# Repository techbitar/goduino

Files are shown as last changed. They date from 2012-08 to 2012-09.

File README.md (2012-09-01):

GOduino III Robot Controller

BACKGROUND

The GOduino III is an Arduino compatible Open Source Hardware robot controller. A while ago, I set out to design a simple robot controller that I can use for both my microcontroller and robotics workshops as well as for my personal tech projects. 

The GOduino III is an Arduino clone. It's built with DIP ICs and through-hole components for ease of assembly and repair.  Also, The GOduino III can be inserted onto a breadboard making it possible to use jumper wires to connect sensors and other parts. The robot controller can handle 2 small servos and 2 DC brushed motors (max 1.2A for each motor).

DESIGNER

Hazim Bitar (techbitar at gmail dot com) 

ORGANIZATION

PIN 13 Protospace (facebook.com/pin13)

DATE

July 12, 2012

CREDIT

Jafar Quttaineh: QA, controller design.
Badr Ghatasheh: QA, variable naming conventions.
Limor Fried: Tutorials and open source products (adafruit.com)

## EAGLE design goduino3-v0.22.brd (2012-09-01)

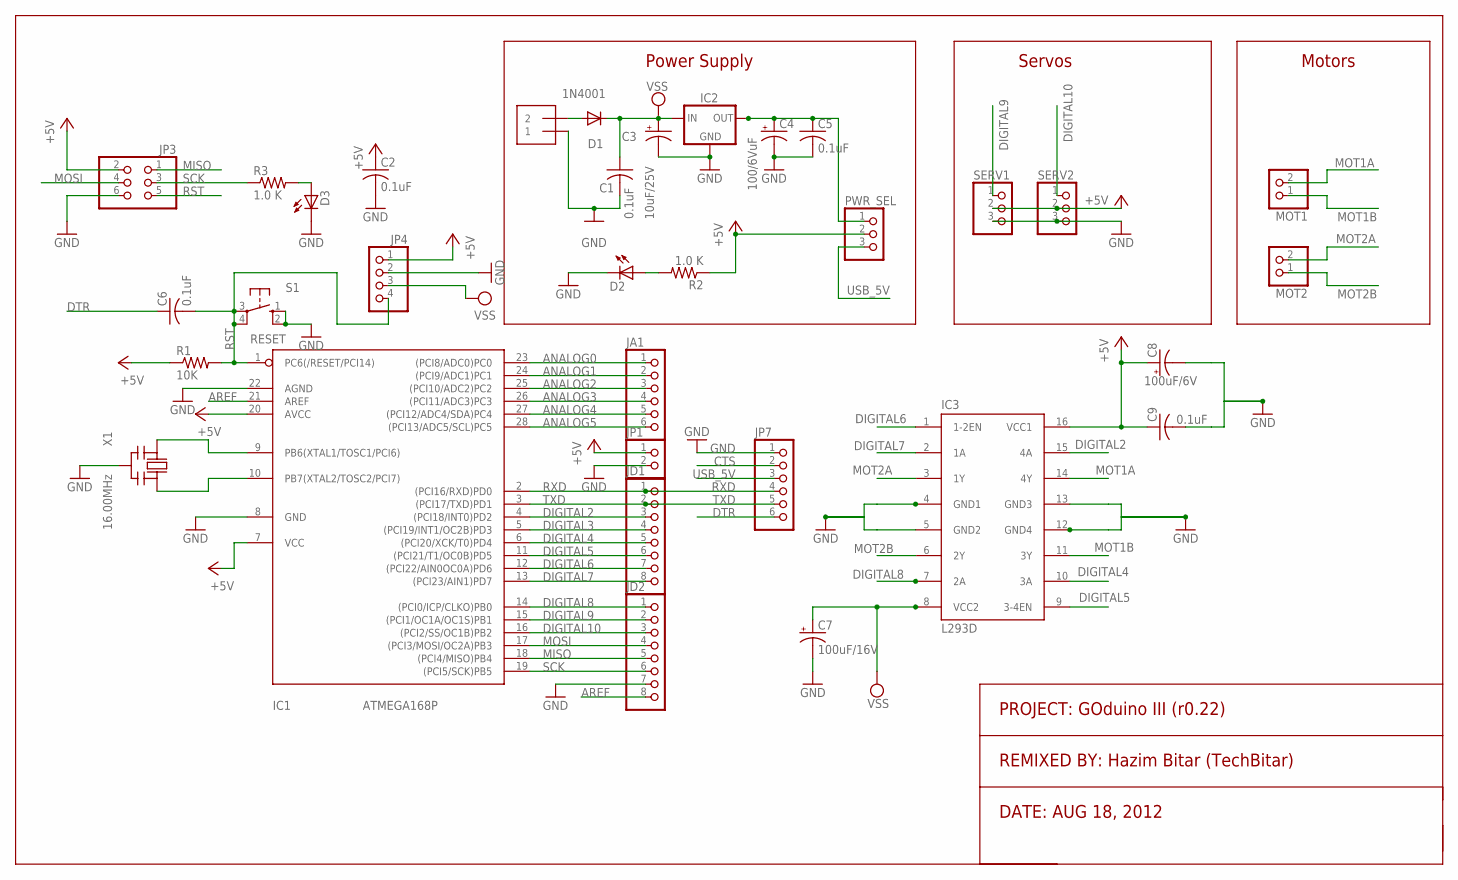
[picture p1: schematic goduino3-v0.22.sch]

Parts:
C1, C2, C5, C6, C9: 0.1uF; C025-025X050
C3: 10uF/25V; E2,5-6
C4: 100/6VuF; E2,5-6
C7: 100uF/16V; E2,5-6
C8: 100uF/6V; E2,5-5
D1: 1N4001; DO41-10
D2: LED3MM
D3: Green; LED3MM
IC1: ATMEGA168P; DIL28/3
IC2: 78XXS
IC3: L293D; DIL16
J2: 1X2-3.5MM
JA1: PINHD-1X6CB; 1X06-CLEANBIG
JD1, JD2: PINHD-1X8CLEANBIG; 1X08-CLEANBIG
JP1: PINHD-1X2CB; 1X02-CB
JP3: PINHD-2X3; 2X03
JP4: PINHD-1X4CB; 1X04-CB
JP7: PINHD-1X6CLEAN; 1X06-CLEAN
MOT1, MOT2: PINHD-1X2CB; 1X02-CB
PWR_SEL: PINHD-1X3; 1X03
R1: 10K; 0207/5V
R2, R3: 1.0 K; 0207/5V
S1: RESET; B3F-10XX
SERV1, SERV2: PINHD-1X3; 1X03
X1: 16.00MHz; CERM_OSC

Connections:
+5V: C2.1, C8.+, C9.1, IC1.7 (VCC), IC1.20 (AVCC), IC3.16 (VCC1), JP1.1, JP3.2, JP4.1, PWR_SEL.2, R1.1, R2.1, SERV1.2, SERV2.2
ANALOG0: IC1.23 ((PCI8/ADC0)PC0), JA1.1
ANALOG1: IC1.24 ((PCI9/ADC1)PC1), JA1.2
ANALOG2: IC1.25 ((PCI10/ADC2)PC2), JA1.3
ANALOG3: IC1.26 ((PCI11/ADC3)PC3), JA1.4
ANALOG4: IC1.27 ((PCI12/ADC4/SDA)PC4), JA1.5
ANALOG5: IC1.28 ((PCI13/ADC5/SCL)PC5), JA1.6
AREF: IC1.21 (AREF), JD2.8
CTS: JP7.2
DIGITAL2: IC1.4 ((PCI18/INT0)PD2), IC3.15 (4A), JD1.3
DIGITAL3: IC1.5 ((PCI19/INT1/OC2B)PD3), JD1.4
DIGITAL4: IC1.6 ((PCI20/XCK/T0)PD4), IC3.10 (3A), JD1.5
DIGITAL5: IC1.11 ((PCI21/T1/OC0B)PD5), IC3.9 (3-4EN), JD1.6
DIGITAL6: IC1.12 ((PCI22/AIN0OC0A)PD6), IC3.1 (1-2EN), JD1.7
DIGITAL7: IC1.13 ((PCI23/AIN1)PD7), IC3.2 (1A), JD1.8
DIGITAL8: IC1.14 ((PCI0/ICP/CLKO)PB0), IC3.7 (2A), JD2.1
DIGITAL9: IC1.15 ((PCI1/OC1A/OC1S)PB1), JD2.2, SERV1.1
DIGITAL10: IC1.16 ((PCI2/SS/OC1B)PB2), JD2.3, SERV2.1
DTR: C6.1, JP7.6
GND: C1.2, C2.2, C3.-, C4.-, C5.2, C7.-, C8.-, C9.2, D2.K (C), D3.K (C), IC1.8 (GND), IC1.22 (AGND), IC2.GND, IC3.4 (GND1), IC3.5 (GND2), IC3.12 (GND4), IC3.13 (GND3), J2.1, JD2.7, JP1.2, JP3.6, JP4.2, JP7.1, S1.1 (S), S1.2 (S1), SERV1.3, SERV2.3, X1.P$2 (GND)
MISO: IC1.18 ((PCI4/MISO)PB4), JD2.5, JP3.1
MOSI: IC1.17 ((PCI3/MOSI/OC2A)PB3), JD2.4, JP3.4
MOT1A: IC3.14 (4Y), MOT1.2
MOT1B: IC3.11 (3Y), MOT1.1
MOT2A: IC3.3 (1Y), MOT2.2
MOT2B: IC3.6 (2Y), MOT2.1
unnamed: IC1.9 (PB6(XTAL1/TOSC1/PCI6)), X1.P$1 (IN)
unnamed: IC1.10 (PB7(XTAL2/TOSC2/PCI7)), X1.P$3 (OUT)
unnamed: D2.A, R2.2
unnamed: D3.A, R3.2
unnamed: C4.+, C5.1, IC2.OUT, PWR_SEL.1
RST: C6.2, IC1.1 (PC6(/RESET/PCI14)), JP3.5, JP4.4, R1.2, S1.3, S1.4 (P1)
RXD: IC1.2 ((PCI16/RXD)PD0), JD1.1, JP7.4
SCK: IC1.19 ((PCI5/SCK)PB5), JD2.6, JP3.3, R3.1
TXD: IC1.3 ((PCI17/TXD)PD1), JD1.2, JP7.5
USB_5V: JP7.3, PWR_SEL.3
VSS: C1.1, C3.+, C7.+, D1.A, D1.C, IC2.IN, IC3.8 (VCC2), J2.2, JP4.3

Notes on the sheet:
Power Supply
Servos
Motors
PROJECT: GOduino III (r0.22)
REMIXED BY: Hazim Bitar (TechBitar)
DATE: AUG 18, 2012

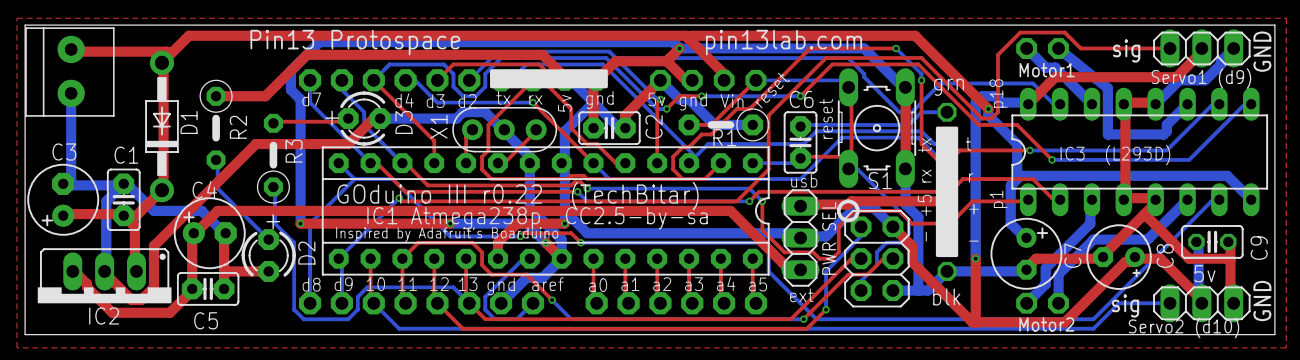
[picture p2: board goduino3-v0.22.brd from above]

Board: 2 copper layers, 99.7 x 24.7 mm, 33 parts (0 on the bottom side), 36 nets.

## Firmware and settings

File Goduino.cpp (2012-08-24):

/*
  File: Goduino.cpp - Library for controlling the GOduino III robot controller.
  Created by: Hazim Bitar (techbitar at gmail dot com)
  Date: August 23, 20012.
  Version: 0.12 beta
  License: Released into the public domain.
*/

#include "Arduino.h"
#include "Goduino.h"

// map motor poles to Arduino pins
#define MOT1_POL1 4  
#define MOT1_POL2 2
#define MOT2_POL1 7
#define MOT2_POL2 8

// map L293d motor enable pins to Arduino pins
#define MOT1_ENA 5
#define MOT2_ENA 6

#define MOT1_MAX_SPEED 1023
#define MOT2_MAX_SPEED 1023

#define MOT_DELAY 30
#define DBG_MOT_SPEED 3000

Goduino::Goduino()
{
  // set mapped motor poles (L293D) to Arduino pins 
  pinMode(MOT1_ENA, OUTPUT);
  pinMode(MOT2_ENA, OUTPUT);

  pinMode( MOT1_POL1 , OUTPUT);
  pinMode( MOT1_POL2, OUTPUT);
  pinMode( MOT2_POL1, OUTPUT);
  pinMode( MOT2_POL2 , OUTPUT);

}

void Goduino::motorStop(uint8_t motorNum){
  delay(MOT_DELAY);
  if (motorNum == 1) {
    digitalWrite(MOT1_POL1, LOW);
    digitalWrite(MOT1_POL2, LOW);
  }
  else if (motorNum == 2) {

    digitalWrite(MOT2_POL1, LOW);
    digitalWrite(MOT2_POL2, LOW);
  }
  delay(MOT_DELAY);
}

void Goduino::motorForward(uint8_t motorNum){
  if (motorNum == 1) {
    digitalWrite(MOT1_POL1, HIGH);
    digitalWrite(MOT1_POL2, LOW);
  }
  else if (motorNum == 2) {

    digitalWrite(MOT2_POL1, LOW);
    digitalWrite(MOT2_POL2, HIGH);
  }
  delay(MOT_DELAY);
}

void Goduino::motorBack(uint8_t motorNum){
  if (motorNum == 1) {
    digitalWrite(MOT1_POL1, LOW);
    digitalWrite(MOT1_POL2, HIGH);
  }  
  else if (motorNum == 2) {
    digitalWrite(MOT2_POL1, HIGH);
    digitalWrite(MOT2_POL2, LOW);
  }
  delay(MOT_DELAY);
}

void Goduino::motorSpeed(uint16_t mot1speed, uint16_t mot2speed) {
  if (mot1speed > MOT1_MAX_SPEED ) mot1speed = MOT1_MAX_SPEED; // limit top speed
  if (mot2speed > MOT2_MAX_SPEED ) mot2speed = MOT2_MAX_SPEED; // limit top speed
  if (mot1speed < 0) mot1speed = 0; // keep motor above 0
  if (mot2speed < 0) mot2speed = 0; // keep motor speed above 0
  analogWrite(MOT1_ENA, mot1speed);
  analogWrite(MOT2_ENA, mot2speed);
}

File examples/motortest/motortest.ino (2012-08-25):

/*
 File: motortest.ino - example sketch to test the GOduino III robot controller.
 Created by: Hazim Bitar (techbitar at gmail dot com)
 Date: August 23, 20012.
 Version: 0.11 beta
 License: Released into the public domain.
 */

#include <Goduino.h>

Goduino myrobot;

void setup() {
  Serial.begin(9600);
  Serial.println("Set speed of both motors to 100 (max 1024)");
  myrobot.motorSpeed(50,50);
}

void loop() {

  Serial.println("TEST PHASE I - SPIN BOTH MOTORS TOGETHER IN SAME DIRECTION");
  delay(3000);

  Serial.println("Spin both motors in one direction (3 sec)");
  myrobot.motorForward(1);
  myrobot.motorForward(2);
  delay(3000);

  Serial.println("Stop both motors for 1 sec");
  myrobot.motorStop(1);
  myrobot.motorStop(2);
  delay(1000);

  Serial.println("Spin both motors in opposite direction (3 sec)");
  myrobot.motorBack(1);	
  myrobot.motorBack(2);	
  delay(3000);

  Serial.println("Stop both motors for 1 sec");
  myrobot.motorStop(1);
  myrobot.motorStop(2);
  delay(1000);

  //=================================================================================

  Serial.println("TEST PHASE II - SPIN EACH MOTOR OPPOSTE OF THE OTHER");
  delay(3000);

  Serial.println("Spin  motor 1 in one direction while motor 2 in opposite direction (3 sec)");
  myrobot.motorForward(1);
  myrobot.motorBack(2);
  delay(3000);

  Serial.println("Stop both motors for 1 sec");
  myrobot.motorStop(1);
  myrobot.motorStop(2);
  delay(1000);

  Serial.println("Spin  motor 2 in one direction while motor 1 in opposite direction (3 sec)");
  myrobot.motorBack(1);	
  myrobot.motorForward(2);	
  delay(3000);

  Serial.println("Stop both motors for 1 sec");
  myrobot.motorStop(1);
  myrobot.motorStop(2);
  delay(1000);

  //=================================================================================

  Serial.println("TEST PHASE III - SPIN EACH MOTOR WHILE THE OTHER IS STOPPED");
  delay(3000);

  Serial.println("Spin motor 1 in one direction while motor 2 is stopped (3 sec)");
  myrobot.motorForward(1);
  myrobot.motorStop(2);
  delay(3000);

  Serial.println("Stop both motors for 1 sec");
  myrobot.motorStop(1);
  myrobot.motorStop(2);
  delay(1000);

  Serial.println("Spin motor 2 in one direction while motor 1 is stopped (3 sec)");
  myrobot.motorForward(2);
  myrobot.motorStop(1);
  delay(3000);
  
  Serial.println("Stop both motors for 1 sec");
  myrobot.motorStop(1);
  myrobot.motorStop(2);
  delay(1000);

  Serial.println("Spin motor 1 in reverse direction while motor 2 is stopped (3 sec)");
  myrobot.motorBack(1);
  myrobot.motorStop(2);
  delay(3000);

  Serial.println("Stop both motors for 1 sec");
  myrobot.motorStop(1);
  myrobot.motorStop(2);
  delay(1000);

  Serial.println("Spin motor 2 in reverse direction while motor 1 is stopped (3 sec)");
  myrobot.motorBack(2);
  myrobot.motorStop(1);
  delay(3000);

  Serial.println("Stop both motors for 1 sec");
  myrobot.motorStop(1);
  myrobot.motorStop(2);
  delay(1000);

}

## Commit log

2012-08-23 changing naming conventions, dir structure, fix typos
    [Goduino.cpp]
2012-08-23 remove files
    [goduino3-v0.21.sch]
2012-09-01 updated eagle files
    [goduino3-v0.22.brd, goduino3-v0.22.sch]
2012-09-01 updated README and created LICENSE files
    [goduino3-v0.21.sch]
